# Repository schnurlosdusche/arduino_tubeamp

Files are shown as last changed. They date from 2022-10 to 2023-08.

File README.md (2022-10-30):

# arduino_tubeamp

<p align="center">
  PRE6H1N
</p>

--------------------------------------------------------------------------------------------------
                                                 DISCLAIMER

!! Attention : Working with mains power or high DC voltages, like in tube amps used,
serious injury might occur or death. Always make sure, the tube amp is free of any
remaining voltage/capacity stored in the circuit (capacitors). You need exactly to know,
what you do when working with mains or high voltages in general !

!! I do not give any warranty, that the information given here is free of errors.
Use these information on your own risk. 

--------------------------------------------------------------------------------------------------

I installed an arduino nano in my selfmade tube-preamp to monitor and control the voltages for 
the tubes. My preamp uses a 6H1N and an EAA91 for each channel. 

The best way to start a tube amp, is to preheat the tubes for a recent time before applying the
higher anode voltage. In my case, a voltage of around 90VDC is used as anode voltage.
Nowerdays (and I guess the future in general), tubes are getting more and more expensive and
sometimes almost impossible to get/buy (especially some kinds). If there is a way, to maximize
their lifespan, this project seems for me to be a logical way. So why not use a technology
that is simple, cheap and easy to build on your own ?

The Nano measures the voltages of 6.3VDC and the 90VDC in the first step after applying mains
power to the preamp. Within 5 seconds, both power supplies should stabilize. Are both voltages within
a certain range, preheating starts. In this time, a connected NeoPixel (WS2812B) LED indicates the
preheating process. After approximately 40 seconds, preheating is finished and the anode voltage
will be switched on and applied to the circuit via a relay.

From that point on, the sketch will measure continously the voltages and if one of them leaves
the predefined range, the automation will switch off heater and anode voltages.

The Neopixel LED indicates the actual status of the preamp. Additionally, a 20x4 Display can be 
connected to read the voltages and the status. If an error occurs like a voltage not in defined range,
a message is shown on the display telling you, which voltage fails and the corresponding value.

The 20x4 display sits in a 3D printed case, that can be mounted when needed. For this, I designed
an easy mount connection, that includes the 4-pin I2C connection. See the provided STL files within this
project. Ths U-shaped part will be fitted to the bottom of the preamp, so the other part can slide 
in and provide a safe connection beside a hold for the display. The rectangular space on both parts
give enough room for a 4-pin "Dupont" connector. On the display side male and the preamp-side female.

<p align="center">
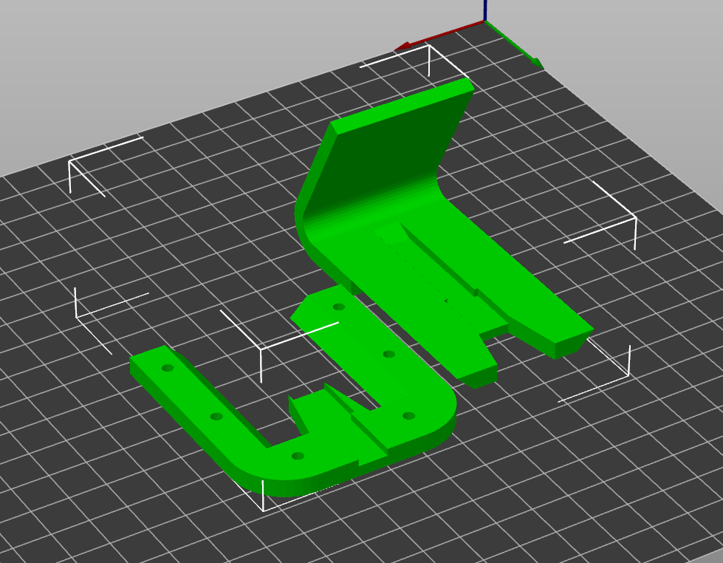
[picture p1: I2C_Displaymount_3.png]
PRE6H1N
  
</p>

In the meantime, I printed a few of these parts and they all fit very well and provide a strong and
simple connection in both ways, electrically and mechanically. There is just no possibility to 
connect the I2C bus in a wrong way... 

I do not provide the case for the display as .stl file, as there are different types of displays
and so, the build volume / size might differ from the one, I use. I simply glued my case for the 
display to the arm, so you can do, too. 

The only requirement regarding the display is the ability, to use an I2C connection for the
communication. You may adjust the code to use a 16x2 character display...

Future plans :

- Switching the pre out ports by relay. Shorten them to ground during preheating and in case of
an error that is detected by the arduino...

- Monitoring the current for the heater and defining the duration of the preheating process depending
on the current (current will be higher when tubes are "cold" and decreases during warm up)
The arduino nano can communicate with a Nodemcu (ESP8266) via the I2C bus and report the voltages 
and the current for long term statistics. I expect to see a slight change in the values over time...
The nodemcu could forward these information via MQTT to a server, where the values can be stored.
The only downside of using a nodemcu so near or inside a tube preamp is the radio frequency from the
WiFi/Bluetooth module. I guess, I have to test that... 

- Finding relays to handle high voltages of appr 360VDC for my other tubeamps... so they can also be 
monitored and controlled.

This project is still a work in progress...

----------------------------------------------------------------------------------------------------

More information will soon be available on my webiste : schnurlosdusche (dot) de

Feel free to get in contact with me : tubes (at) schnurlosdusche (dot) de

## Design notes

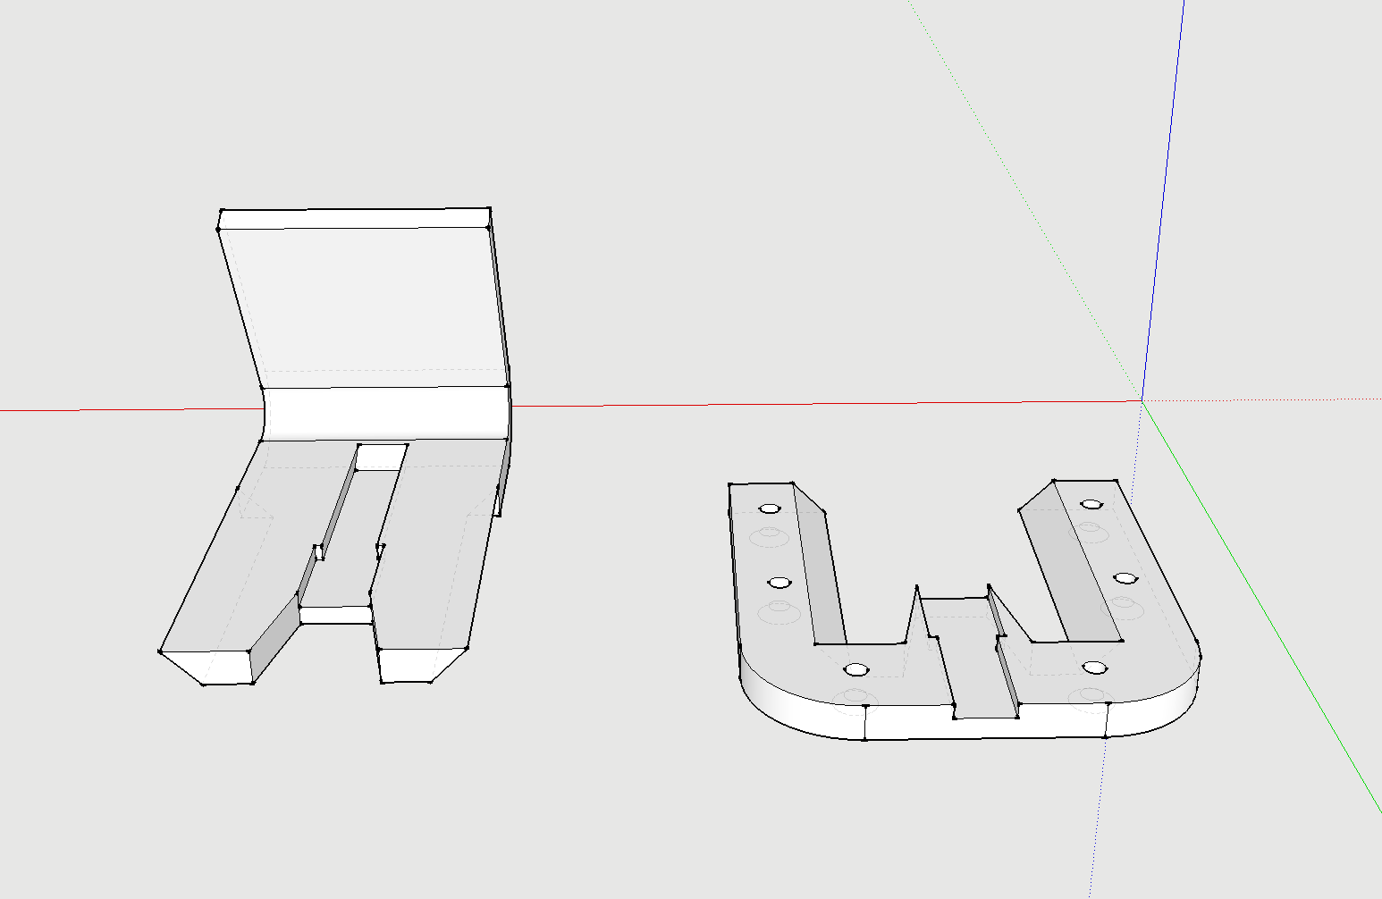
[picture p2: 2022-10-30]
I2C_Displaymount_1.png

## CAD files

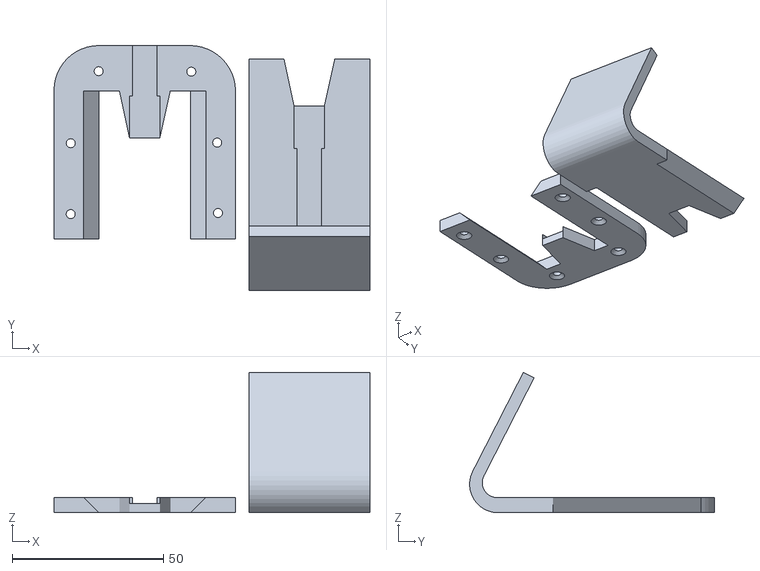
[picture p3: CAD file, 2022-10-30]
I2C_Displaymount.stl
104.5 x 80.9 x 46.4

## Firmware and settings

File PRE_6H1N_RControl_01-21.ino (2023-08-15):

// PreAmp 6H1N - Relay Controller Arduino Nano V0.1.21

#include <Arduino.h>
#include <HardwareSerial.h>
#include <Wire.h>
#include <LiquidCrystal_I2C.h>
#include <FastLED.h>

#define DATA_PIN    6			// Data pin for NeoPixel LED
#define LED_TYPE    WS2812B		// Type of LED
#define COLOR_ORDER GRB			// Color mode
#define NUM_LEDS    1			// only using 1 LED in this project
#define FRAMES_PER_SECOND  120		

CRGB leds[NUM_LEDS];
int BRIGHTNESS = 96;			// change this value for the LED brightness (0-255)
int ORIG_BRIGHTNESS;
int DIM_BRIGHTNESS;

const word ANODE_RELAY_PIN = A2;	// Pins for controlling the relay boards
const word HEATER_RELAY_PIN = A3;	// ..
const word HEATER_PIN = A6;		// Pins for measuring the voltages ( each over a voltage devider )
const word ANODE_PIN = A7;		// ..

int a=0;
int i=0;

float HEATER_MIN_VALUE = 6.0;           // acc to datasheet of tube 6H1N min 6.0V
float NORMAL_HEATER_MAX_VALUE = 6.7;    // acc to datasheet of tube 6H1N max 6.6V
float INITIAL_HEATER_MAX_VALUE = 7.3;	// set to NORMAL_HEATER_MAX_VALUE if your power supply is stabilized to 6.3V.
					// My power supply outputs a voltage around 7V without any load,
					// so very often I get an overvoltage error. With load applied
					// (HEATER relay active), the voltage drops back to the desired range... 
float ANODE_MIN_VALUE = 80.0;		// lower end of anode voltage range (for this particular preamp !)  
float ANODE_MAX_VALUE = 91.5;		// upper end of anode voltage range (for this particular preamp !)
float HEATER_VALUE;			// variable for the measured voltage
float ANODE_VALUE;			// ..
float LOAD_PERCENTAGE;			// percentage value during preheating process (will be shown in display)

char ERROR_MSG_1[21] = "ERR - Heater Voltage";
char ERROR_MSG_2[21] = "ERR - Anode Voltage";

bool HEATER = false;			// false = voltage not in range | true = voltage within range
bool PREHEATING = false;		// preheating ready ? status of preheating
bool ANODE = false;			// false = voltage not in range | true = voltage within range

LiquidCrystal_I2C lcd(0x27,20,4);	// initialize the I2C bus for the 20x4 display. 
					// set the HEX address to your needs (e.g. 0x30)

void setup() 
{
  FastLED.addLeds<LED_TYPE,DATA_PIN,COLOR_ORDER>(leds, NUM_LEDS).setCorrection(Tungsten40W);

  ORIG_BRIGHTNESS = BRIGHTNESS;
  DIM_BRIGHTNESS = BRIGHTNESS;
	
  pinMode(ANODE_RELAY_PIN, OUTPUT);	// set mode of PINS
  pinMode(HEATER_RELAY_PIN, OUTPUT);	// ..
  pinMode(ANODE_PIN, INPUT);		// ..
  pinMode(HEATER_PIN, INPUT);		// ..

  digitalWrite(ANODE_RELAY_PIN, LOW);	// make sure, both relays are in OFF state / connection is open
  digitalWrite(HEATER_RELAY_PIN, LOW);	// ..
	
  FastLED.setBrightness(ORIG_BRIGHTNESS);
  leds[0] = CRGB::Blue;			// set LED color BLUE on start
  FastLED.show();			// ..
  
  lcd.init();				// initialize the display
  lcd.backlight();			// turn on the backlight of the display
    
  lcd.setCursor(6,0); 			// set cursor to position...
  lcd.print("PRE6H1N");			// and show something
  lcd.setCursor(3,2);			// ..
  lcd.print("Version 0.1.22");		// ..
  
  delay(5000);

  lcd.setCursor(0,2); 			// set cursor
  lcd.print("checking voltages...");

  // wait max 30 seconds (60 x 500ms) to let the voltages stabilize. 
  // If that fails, LED flashes red in a deadlock and shows message on display

  // If the voltages got stabilized within the defined range and time, set HEATER and ANODE
  // true (done in "readOutVoltages") to interrupt the "while loop" and continue with the normal operation 
  while (( i < 60 ) && ((HEATER == false) && (ANODE == false))) 
      {
        readOutVoltages();
        delay(500);
  	lcd.setCursor(0,1); 		// set cursor
        lcd.print("waiting for voltages");
        lcd.setCursor(0,2); 		// set cursor
        lcd.print("to stabilize...     ");
        i++;
      }

  // if the counter exceeds 59 (almost half a minute), guess the power supply to be faulty or
  // at least, having a bad day or problem :(
  if ( i > 59 )
      {
        while (i)			// a never ending loop (deadlock)
          {
            lcd.setCursor(0,1); // set cursor to 1st symbol of 1st line
            lcd.print("ERROR - Voltages not");
            lcd.setCursor(0,2); // set cursor to 1st symbol of 2nd line
            lcd.print("in defined range  :(");

	    // start flashing the LED red... forever and ever... 
	    // the preamp must be turned off and on to reset this state
            FastLED.setBrightness(128);
            leds[0] = CRGB::Red;
            FastLED.show();
            delay(150);
            FastLED.setBrightness(0);
            leds[0] = CRGB::Black;
            FastLED.show();
            delay(850);
          }
      }

  // if at least the HEATER is true (voltage in range), start the preheating process.
  // In this case, it is more important to have a correct HEATER VOLTAGE than ANODE VOLTAGE !
  if (HEATER == true)
  {
      preheating();
  }

}

// main loop. this is for the normal operation
void loop() 
{
  readOutVoltages();

  if ((ANODE == true)&&(HEATER == true))
    { 
      if (PREHEATING == true)	 
        {
          FastLED.setBrightness(48);
          leds[0] = CRGB::Green;
          FastLED.show();
        
          digitalWrite(ANODE_RELAY_PIN, HIGH); 
          RELAY_ANODE = true;
          digitalWrite(HEATER_RELAY_PIN, HIGH);
          RELAY_HEATER = true;
          delay(500); 
        }
      else
        {
          if (HEATER == true)
          {
            preheating();
          }
            
        }
    }
     else
	{ 
        FastLED.setBrightness(BRIGHTNESS);
        leds[0] = CRGB::Red;
        FastLED.show();
        
        digitalWrite(ANODE_RELAY_PIN, LOW); 
        RELAY_ANODE = false;
        digitalWrite(HEATER_RELAY_PIN, LOW);
        RELAY_HEATER = false;
        
        delay(500); 

      lcd.setCursor(0,2); 
      lcd.print("                    ");
      lcd.setCursor(0,3); 
      lcd.print("                    ");
      
      if ( HEATER == false ) 
      {
        lcd.setCursor(0,1); 
        lcd.print(ERROR_MSG_1); 
      }
      if ( ANODE == false ) 
      { 
        lcd.setCursor(0,2); 
        lcd.print(ERROR_MSG_2);
      }
           
      while ( 1 != 0)                 // dead lock with red blinking LED
      {
        FastLED.setBrightness(255);
        leds[0] = CRGB::Red;
        FastLED.show();
        delay(150);
        FastLED.setBrightness(0);
        leds[0] = CRGB::Black;
        FastLED.show();
        delay(850);
      }
    }
	
	delay(100);
	}
  
void readOutVoltages()
{

  // If the preamp has an unstabilized power supply for the HEATER,
  // a higher voltage during unloaded condition might occur, that prevents the
  // process to start the preheating (as it thinks, the HEATER voltage is too 
  // high). But when load is applied by the HEATER coils, the voltage drops
  // back to normal range. For this case, we use an additional variable with
  // a slightly higher MAX VOLTAGE.
	
  if ( PREHEATING == false )
  	{ HEATER_MAX_VALUE = INITIAL_HEATER_MAX_VALUE; }
  else
  	{ HEATER_MAX_VALUE = NORMAL_HEATER_MAX_VALUE; } 	
	
  HEATER_VALUE = analogRead(HEATER_PIN); // Probe Input
  HEATER_VALUE = HEATER_VALUE * (5.0 / 1023); HEATER_VALUE = (HEATER_VALUE * 1.525);
  ANODE_VALUE = analogRead(ANODE_PIN); // Probe Input
  ANODE_VALUE = ANODE_VALUE * (5.0 / 1023); ANODE_VALUE = (ANODE_VALUE * 21.438);
 
  if (( HEATER_VALUE >= HEATER_MIN_VALUE )&&( HEATER_VALUE <= HEATER_MAX_VALUE )) { HEATER = true; }  else { HEATER = false; }
  if (( ANODE_VALUE >= ANODE_MIN_VALUE )&&( ANODE_VALUE <= ANODE_MAX_VALUE )) { ANODE = true; } else { ANODE = false; }

  lcd.setCursor(2,3);
  lcd.print("H:");
  lcd.print(HEATER_VALUE);      
  lcd.print("V   A:");
  lcd.print(ANODE_VALUE);
  lcd.print("V");
}

void preheating()
{
    lcd.setCursor(0,1);
    lcd.print("                    ");
    lcd.setCursor(2,2);
    lcd.print("preheating tubes  ");
    
    digitalWrite(HEATER_RELAY_PIN, HIGH);       // switch on relay for heater
    ORIG_BRIGHTNESS = BRIGHTNESS;		

    readOutVoltages;

  for ( a = 0; a <= 21; a ++)
  {
    while ( DIM_BRIGHTNESS > 10)
      {
        FastLED.setBrightness(DIM_BRIGHTNESS);
        leds[0] = CRGB::Orange;
        FastLED.show();
        DIM_BRIGHTNESS--;
        delay(15);
      }

    while ( DIM_BRIGHTNESS <= ORIG_BRIGHTNESS )
      {
        FastLED.setBrightness(DIM_BRIGHTNESS);
        leds[0] = CRGB::Orange;
        FastLED.show();
        DIM_BRIGHTNESS++;
        delay(15);
      }

      // the factor 4.6 is needed to calculate the shown percentage of the preheating
      // process
      LOAD_PERCENTAGE = ( a * 4.6 );
      lcd.setCursor(17,2);
      lcd.print(LOAD_PERCENTAGE,0); lcd.print("%");
    
      readOutVoltages;
  }

  #define BRIGHTNESS ORIG_BRIGHTNESS		// after dimming during preheat, set original brightness

    lcd.setCursor(0,2);
    lcd.print("preheating finished ");
      delay(2000);
    lcd.setCursor(0,2);
    lcd.print("                           ");

    PREHEATING = true;
}
